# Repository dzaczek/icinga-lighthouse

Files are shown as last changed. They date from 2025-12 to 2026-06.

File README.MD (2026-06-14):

# Icinga-lighthouse 🚨
**A robust, industrial-grade ESP32 monitor for Icinga2, running on LilyGO T-Relay.**

Image ilustration project

icinga-lighthouse turns a LilyGO T-Relay board into a physical alarm system for your infrastructure. It monitors both Services (Critical) and Hosts (Down) through the **Icinga DB Web JSON API** (Icinga *Web*, not the Icinga 2 core API) — so acknowledged, in-downtime and flapping problems are filtered out server-side and never trip the siren. A problem must also be confirmed over several consecutive polls before the siren (Relay 1) fires, with a smart reminder logic afterwards.
-----

## 🌟 Key Features

  * **Dual Monitoring:** Checks the Icinga DB Web API for *Critical Services* AND *Down Hosts*.
  * **Noise-free by design:** Server-side filters (`is_acknowledged=n`, `in_downtime=n`, `is_flapping=n`) mean acknowledged / muted / flapping problems are ignored.
  * **Confirmation threshold:** A problem must be seen *N* polls in a row (default **3**, configurable) before the siren fires — debounces transient/false positives. While confirming, the device polls at a faster "recheck" cadence instead of waiting a full interval.
  * **Business-hours schedule:** Optionally mute the siren outside a schedule of up to 4 day+hour blocks (e.g. Mon–Fri 06–18 *and* Sat 08–14). Alerts are still shown; only the relay is silenced. Clock from Icinga's HTTP `Date` header (no NTP).
  * **Smart Alarm Logic:**
    1.  **Initial Alarm:** Continuous siren for a set time (e.g., 30s).
    2.  **Cooldown:** Silence to preserve sanity.
    3.  **Reminder:** Short bursts (e.g., 15s) every few minutes if the issue persists.
  * **Safe Mode Architecture:**
      * **No Bootloops:** Connection failures do not crash the device.
      * **Brownout Protection:** Disabled brownout detector to handle power spikes from relays.
      * **Heap JSON:** Uses dynamic memory allocation to prevent stack overflows.
  * **Ethernet (W5500) with WiFi fallback:** Auto-detects the LilyGo T-Relay W5500 shield (H671); if present it is used automatically, otherwise the device falls back to WiFi. Selectable in the panel (Auto / Disabled).
  * **Web Configuration Panel:** Fully configurable via a responsive Web UI (WiFi, Ethernet, URLs, Timings, Language).
  * **Multi-language:** Dictionary-based support for **English** and **Polish**.
  * **Manual Test Mode:** Physical buttons in Web UI to toggle relays manually (pauses automation for 60s).

-----

## UX

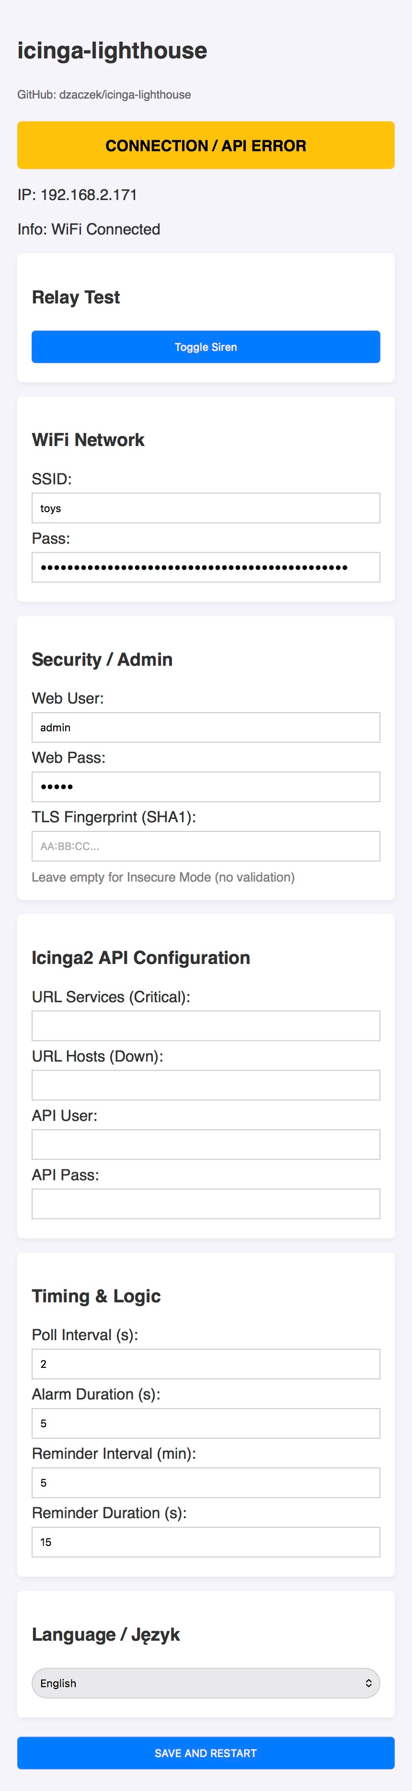
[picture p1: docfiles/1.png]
Image ux


## 🛠️ Hardware & Pinout

**Device:** LilyGO T-Relay (4-Channel ESP32)

| Component | GPIO Pin | Description |
| :--- | :--- | :--- |
| **Relay 1** | **GPIO 21** | **Main Alarm (Siren/Light)** |
| Relay 2 | GPIO 19 | *Disabled / Spare* |
| Relay 3 | GPIO 18 | *Disabled / Spare* |
| Relay 4 | GPIO 05 | *Disabled / Spare* |
| **Status LED** | **GPIO 25** | System Heartbeat / Error Indicator |

### 🔌 Wiring the Siren

> 📐 Full **power & beacon wiring diagram** (24 V supply, mains switch, Osram beacon):
> [`docs/wiring.md`](docs/wiring.md).

Connect your visual/audio signaling device to **Relay 1**:

1.  Connect Power Source (+) to **COM** (Common).
2.  Connect Siren (+) to **NO** (Normally Open).
3.  *The siren will only activate when the alarm is triggered.*

### 🌐 Ethernet — LilyGo T-Relay W5500 Shield (H671)

Plug in the W5500 shield and the device uses wired Ethernet automatically
(DHCP), falling back to WiFi if the shield is absent or the cable is unplugged.
It can be forced off in the panel (Ethernet mode → *Disabled*). Pinout (T-Relay-4):

| W5500 | GPIO | | W5500 | GPIO |
| :--- | :--- | :--- | :--- | :--- |
| SCLK | 22 | | CS | 27 |
| MISO | 13 | | RST | 23 |
| MOSI | 26 | | INT | 36 |

> These pins do not collide with the relays (21/19/18/5) or status LED (25).
> Uses the WIZnet **Ethernet** Arduino library (the ESP32 core 2.x built-in
> `ETH` has no SPI/W5500 support). icingadb-web is queried over plain HTTP on
> the Ethernet path.

-----

## 🧠 Application Logic (Mermaid Diagram)

This flowchart illustrates the core loop of the `icinga-lighthouse` firmware.

```mermaid
graph TD
    Start([System Boot]) --> Init[Disable Brownout & Init WiFi]
    Init --> Loop{Main Loop}

    %% Status LED Logic
    Loop --> LED[Update Status LED]
    LED -- Fast Blink --> ErrState[Error / No Connection]
    LED -- Slow Blink --> OKState[System OK]

    %% Manual Override Check
    Loop --> ManCheck{Manual Mode?}
    ManCheck -- Yes --> WebCtrl[Handle Web Buttons Only]
    WebCtrl --> Loop

    %% Automatic Logic
    ManCheck -- No --> WiFiCheck{WiFi Connected?}
    
    WiFiCheck -- No --> SetErr[Set Network Error Flag]
    WiFiCheck -- Yes --> PollTime{Poll Interval?}
    
    PollTime -- No --> Logic
    PollTime -- Yes --> CheckSvc[GET Icinga Services]
    
    CheckSvc -- Critical Found --> AlarmSet[Set Alarm ACTIVE]
    CheckSvc -- OK --> CheckHost[GET Icinga Hosts]
    
    CheckHost -- Down Found --> AlarmSet
    CheckHost -- OK --> AlarmClear[Set Alarm INACTIVE]
    
    %% Relay Logic Machine
    AlarmSet --> Logic
    AlarmClear --> Logic
    SetErr --> Logic
    
    subgraph Relay State Machine
    Logic[Update Relay Logic] --> StateCheck{Current State}
    StateCheck -- Idle --> R_Idle[Relay OFF]
    R_Idle -- Alarm Active --> R_Init[Relay ON - Initial]
    R_Init -- Time limit reached --> R_Cool[Relay OFF - Cooldown]
    R_Cool -- Reminder time reached --> R_Rem[Relay ON - Reminder]
    R_Rem -- Time limit reached --> R_Cool
    end
    
    Logic --> Loop
```

-----

## 🚦 Status Indicators

The onboard LED (GPIO 25) indicates the current health of the monitor:

  * **🟢 Slow Blink (1s):** System OK. Connected to WiFi and Icinga API reachable.
  * **🔴 Fast Blink (0.2s):** Error. WiFi disconnected OR Icinga API unreachable (check IP/Port).

-----

## ⚙️ Configuration Guide

1.  Connect the device to power.
2.  If not configured, connect to WiFi AP: `icinga-lighthouse-cfg` (Pass: `admin123`).
3.  Open `http://192.168.4.1` (or the assigned IP if connected to your router).
4.  Login (Default: `admin` / `admin`).

### API Setup

The device talks to **Icinga Web 2 / Icinga DB Web** (default port 8080), using HTTP Basic auth with an Icinga Web login. `http://` and `https://` are both supported (https uses an insecure/no-verify TLS connection). `limit=1` keeps the response tiny — the device only needs to know whether *any* unhandled problem exists.

  * **Services URL:** unhandled CRITICAL services.
      * *Example:* `http://192.168.1.100:8080/icingadb/services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`
  * **Hosts URL:** unhandled DOWN hosts.
      * *Example:* `http://192.168.1.100:8080/icingadb/hosts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`
  * **Web User / Pass:** an Icinga Web 2 login (e.g. `admin` / `admin` in the test-env).

> Note: Icinga DB Web is served at the web root (`/icingadb/...`), not under `/icingaweb2/...`, on the official container image.

### Timings & Logic

  * **Poll Interval:** normal query cadence (e.g. 30s).
  * **Fast recheck on problem:** while a fresh problem is being confirmed, poll this fast instead (e.g. 10s).
  * **Confirm threshold:** consecutive problem polls required before the siren fires (default 3).
  * **Alarm Duration:** how long the siren screams initially (e.g., 30s).
  * **Reminder Interval:** how often to remind if the error persists (e.g., every 5 min).
  * **Reminder Duration:** how long the reminder scream lasts (e.g., 15s).

### Business Hours (siren schedule)

The siren can be restricted to a schedule built from up to **4 time blocks**. Each block
is a set of days (tick **Mon–Sun** individually) plus an hour window (**From/To**, To is
exclusive, and To < From spans midnight). The siren is allowed when *now* matches **any**
block — so you can mix rules like *Mon–Fri 06:00–18:00* **and** *Sat 08:00–14:00*. A block
with no days ticked is off; with the whole schedule off the siren runs 24/7.

Alerts are still *detected and shown* in the UI outside the schedule; only the relay is
kept silent. The device clock comes from the **HTTP `Date` header** of Icinga's replies
(works over WiFi and Ethernet alike — no NTP); set the **UTC offset** for your local time.

-----

## 🚀 Deployment

The firmware is a single Arduino sketch (`trelaylaatern.ino`) for the ESP32. Flash it
with **PlatformIO** (CLI, scriptable) or the **Arduino IDE**. Libraries: `ArduinoJson`
(always) and `Ethernet` / WIZnet (only for the W5500 shield).

### Quick start — helper scripts (macOS / Linux)

Two scripts wrap the whole flow (they generate an isolated PlatformIO project in
`.build/`, which is gitignored):

```bash
./build.sh                 # compile only
./flash.sh                 # build + auto-detect the serial port + upload
./flash.sh --monitor       # ...and open the serial monitor afterwards
./flash.sh --erase         # also wipe NVS (clears saved WiFi/Icinga config)
./flash.sh /dev/ttyUSB0    # force a specific port (or set PORT=...)
```

`flash.sh` auto-detects the port (`cu.usbserial*` / `SLAB` / `wchusbserial` on macOS,
`ttyUSB*` / `ttyACM*` on Linux). Needs PlatformIO: `brew install platformio` or
`pipx install platformio`. The manual steps below do the same thing by hand.

### Option A — PlatformIO CLI (macOS / Linux / Windows)

```bash
# 1) Install PlatformIO Core
#    macOS:  brew install platformio        (or: pipx install platformio)
#    Linux:  pipx install platformio        (or: pip install --user platformio)

# 2) Create a project that points at this sketch
mkdir -p build/src && cp trelaylaatern.ino build/src/main.ino
cat > build/platformio.ini <<'INI'
[env:esp32dev]
platform = espressif32
board = esp32dev
framework = arduino
monitor_speed = 115200
upload_speed = 115200          ; some USB-serial bridges fail at 921600
lib_deps =
  bblanchon/ArduinoJson@^6.21.3
  arduino-libraries/Ethernet@^2.0.2
INI

# 3) Find the serial port
#    macOS:  ls /dev/tty.usbserial-*   or  /dev/tty.SLAB_USBtoUART
#    Linux:  ls /dev/ttyUSB*           (add yourself to the 'dialout' group)

# 4) Build, flash, watch the log
cd build
pio run                                              # compile
pio run -t upload --upload-port /dev/tty.usbserial-XXXX
pio device monitor -b 115200 -p /dev/tty.usbserial-XXXX
```

> Tip: a fresh board boots into a WiFi access point `icinga-lighthouse-cfg`
> (password `admin123`); open `http://192.168.4.1` to configure it. To start from
> known defaults instead, wipe stored settings first: `pio run -t erase`.

### Option B — Arduino IDE (macOS / Linux / Windows)

1. Install the **ESP32 board package** (Boards Manager → "esp32" by Espressif).
2. Install libraries (Library Manager): **ArduinoJson**, and **Ethernet** (WIZnet) for the shield.
3. Board: **ESP32 Dev Module**. Port: your USB-serial device.
4. Open `trelaylaatern.ino` and click **Upload**.

### Option C — flash a prebuilt binary with esptool (any OS)

```bash
pip install esptool
esptool.py --port /dev/tty.usbserial-XXXX --baud 115200 write_flash 0x10000 firmware.bin
```

### First-run configuration

1. Connect to the AP `icinga-lighthouse-cfg` (or reach the device IP if it already has
   Ethernet/WiFi) and open the web panel (default login `admin` / `admin`).
2. Set WiFi (or just plug in the W5500 shield for auto Ethernet), the Icinga DB Web URLs
   + login, timings, confirm threshold, and business hours. Save → the device reboots.

### Try it without hardware (Docker/Podman test-env)

A full Icinga DB stack **and** a virtual ESP32 running this exact firmware are in
[`test-env/`](test-env/README.md):

```bash
cd test-env
docker-compose --profile icinga up -d --build   # Icinga DB stack (web on :8080)
./scripts/seed.sh                               # test objects
docker-compose --profile sim up -d --build      # virtual ESP32
./scripts/set-critical.sh                       # fire an alert; watch the relay react
docker logs -f il-esp32-sim | grep -E 'checkIcinga|RELAY'
```

-----

## 🔒 Security notes

- **Brute-force protection:** the web panel throttles every failed login (~0.8 s) and
  locks out after 5 wrong attempts in a row for 60 s (HTTP 429). The lockout is global
  and auto-expires — a sustained guessing attack briefly locks the panel for everyone,
  which is the intended trade-off on a single-admin device.
- **Change the defaults.** Panel login defaults to `admin` / `admin` and the setup AP to
  `admin123`; set your own in the panel (Security / Admin) and WiFi sections.
- **Transport is plaintext.** The panel and the Icinga DB Web polling run over HTTP (the
  ESP32 has no practical TLS server). Keep the device on a trusted VLAN/segment; the
  config AP and basic-auth credentials are sniffable on the local link.

## 🗼 3D-printable lantern

The [`lighthouse3d/`](lighthouse3d/) folder holds the printable lighthouse enclosure that
houses the board — STL parts (base, towers, door, stairs, feet), the assembled STEP model,
a CadQuery source script, and a render preview. Slicing guide (Bambu Studio):
[`lighthouse3d/slicer.md`](lighthouse3d/slicer.md).

## 📝 License

[https://github.com/dzaczek/icinga-lighthouse](https://github.com/dzaczek/icinga-lighthouse)

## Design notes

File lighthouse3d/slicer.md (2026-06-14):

# Printing guide — Bambu Studio (lighthouse parts)

How to slice the lantern parts (especially `04_wieza_gorna.stl`, the upper tower with the
platform, corbel and cable funnel) cleanly. The whole job comes down to **one setting** —
the support **Threshold angle** — plus a note on the screw-insert bosses.

## TL;DR

| Setting | Value |
| :--- | :--- |
| Orientation | **default** — frame/ring flat on the plate, platform up. **Do not flip.** |
| Parameter mode | **Advanced / Expert** (to see the support sub-settings) |
| Layer height | 0.2 mm |
| Walls | 3 wall loops |
| Support | **On**, type **`normal(auto)`** |
| **Support → Threshold angle** | **25°** (drop to 20° if any support still shows under the platform) |
| On build plate only | **OFF** |
| Part cooling (overhang) | PLA ~100 % · PETG ~40–60 % |
| Overhang slow-down | ON, steepest band ~20–30 mm/s |
| Brim | none (the ring gives a big first layer); 3–5 mm only if an edge lifts |

---

## 1. Import & orient

Import `04_wieza_gorna.stl` (or the STEP). **Leave it as-is**: split/frame ring on the plate
at z = 0, platform + railing pointing up. Don't rotate or flip — that orientation is what makes
the funnel self-supporting once the threshold is set.

## 2. Show all options

Top-right, set the parameter mode to **Advanced** (or **Expert**) so the support sub-settings
are visible.

## 3. Filament & quality

Pick your filament (PETG or PLA). 0.2 mm layer height, **3 wall loops**. Infill to taste
(15–20 % gyroid is plenty for an enclosure).

## 4. Support — the key step

Support tab → **Support: On**, **Type: `normal(auto)`**.

**Threshold angle: `25°`.**

> **Why.** Bambu generates support for a surface when its slope **to the bed** is *below* the
> threshold. The funnel/corbel under the platform sit at **~31° from the bed** (≈59° from
> vertical) — right on top of the **~30° default**. Because a curved cone is a mesh of facets,
> some land just under 30° and some just over, so you get **flaky, partial** support smeared
> over the cone. Setting the threshold to **25°** puts the *entire* cone safely above it, so it
> is left support-free, while genuinely flat spots (window-top lintels, platform outer rim,
> railing tops — all ~0° from the bed) still get supported.

- Leave **Top Z distance / XY distance** at the profile defaults.
- **Do not** tick **“On build plate only”** — the small support under the platform rim needs to
  rest on the corbel below it, not the plate.

## 5. Overhang cooling

So the 59°-from-vertical funnel prints clean without support:

- **Cooling:** part-cooling fan high for overhang regions — **PLA ~100 %**, **PETG ~40–60 %**
  (keep PETG moderate so you don't kill layer adhesion).
- **Overhang slow-down:** enable it; put the steepest band around **20–30 mm/s**.
- Optional: raise *min layer time* so thin upper layers get more cooling.

## 6. Slice & verify (don't skip)

Slice → **Preview** → switch to the support/overhang view, then check:

- ✅ **No support columns under the platform** (the funnel/corbel cone). If any remain, lower
  **Threshold angle to 20°**.
- ✅ Support appears **only** at: window-top lintels, the platform outer rim, and railing tops —
  all reachable from outside/top, nothing trapped inside.
- ✅ Scrub the layer slider through the funnel region (≈ z 135–165) and confirm it slices as a
  clean, self-supporting cone.

## 7. Manual cleanup (optional)

- Unwanted auto-support → **Support painting → eraser**, or drop a **Support blocker** over it.
- A flat spot got missed → **Support enforcer**.

## 8. Screw-insert bosses — and dissolvable support

The threshold trick removes support from the funnel; the *remaining* supports are all
**external** (lintels, rim, railing) and snap off by hand — **no soluble filament needed there.**

### Fasteners in this model

The model already uses print-friendly fixing, so **most nut/screw features need no support**:

| Feature | Where | Geometry | Printing |
| :--- | :--- | :--- | :--- |
| **M3 captive-nut slots** | tower↔base tabs, tower-section tabs | horizontal slot **5.75 × 2.8 mm**, nut **slides in** from the bolt hole | **No support** — the 2.8 mm-tall slot bridges only 5.75 mm. Print, then slide the M3 nut in sideways. |
| **M3 heat-set inserts** | upper tower-section tab (Ø4 hole) | straight cylindrical hole | **No support** — melt the brass insert in afterwards. |
| **M6 hex nut pockets** | platform underside, ×3 (lamp mount) | Ø12 hex × **5.6 mm deep**, opens **downward**; central Ø6.6 hole; **roof chamfered to a ~48° cone** | **No support** — the conical roof is self-supporting printed bottom-up. The captive press-fit nut seats on the cone (fine for a light beacon). |

So in practice you **don't** need dissolvable filament for the nuts at all — the M3 slots bridge,
the inserts are straight holes, and the M6 pockets now have a **self-supporting chamfered roof**
(done in [`latarnia_cadquery.py`](latarnia_cadquery.py); the flat ledge was replaced by a ~48° cone).

Soluble/breakaway support is only worth it if a **screw boss traps support inside a blind/deep
cavity** you can't reach. First decide which case you have:

| Insert type | Hole geometry | Needs support? |
| :--- | :--- | :--- |
| **Heat-set threaded insert** (brass, melted in) | straight cylindrical hole, no roof | **No** — print it open, no support, no soluble filament |
| **Captive nut pocket** (hex pocket with a roof) | overhanging roof over a cavity | Yes — and it's hard to clear → soluble/breakaway helps |
| **Self-tapping screw straight into plastic** | plain pilot hole | No |

**Recommended order (cheapest/easiest first):**

1. **Design it out.** Use heat-set inserts in straight holes (zero overhang → zero support), or
   make captive-nut roofs a self-supporting chamfer / teardrop, or open the pocket to one side.
2. **Breakaway interface.** On a multi-material setup (AMS / dual), set only the **support
   interface** to a breakaway material (Bambu *“Support for PLA/PETG”*) and the support **body**
   to your main filament. It releases cleanly from a pocket without water.
3. **Water-soluble (PVA)** — true “dissolve it out”. Use it **only as the support interface**
   (top/bottom interface layers), main filament for the body, to save the (expensive,
   hygroscopic) PVA. Then soak the part in warm water until it dissolves.

**If you go PVA / soluble:**

- Needs a **multi-material printer** (AMS + a printer that allows soluble support, e.g. X1/P1
  with the AMS) — a single-extruder print can't mix two materials.
- Support tab → enable **Support interface**, set **“Interface filament” = PVA** (or breakaway),
  **“Support base filament” = main**. A few interface layers is enough.
- PVA is **hygroscopic** — dry it before use and keep it sealed, or it strings/clogs.
- Temperatures: PVA prints ~**190–215 °C**. It pairs easily with **PLA**; with **PETG** the temp
  gap is larger, so prefer the **breakaway** interface for PETG parts, or print PVA at the low
  end and slow.
- Dissolving is **slow** (warm water, often hours, agitation/replacing water speeds it up).

> Bottom line: for this lantern you most likely **don't** need soluble filament — the funnel is
> handled by the threshold angle, and screw fixing is cleanest with **heat-set inserts in
> straight holes** (no support at all). Reserve PVA/breakaway for genuinely trapped pockets.

## 9. Bed adhesion

The frame ring gives a large first-layer contact area, so adhesion is solid — **no brim needed**
unless an edge lifts, then add a **3–5 mm brim**.

## 10. Alternative — fix it in CAD instead of the slicer

If you'd rather not touch slicer settings on every print, lower `PLUG_BOT_Z` in
[`latarnia_cadquery.py`](latarnia_cadquery.py) so the funnel becomes ~50° from vertical —
self-supporting even at the **default 30°** threshold — and regenerate the STL. Likewise, model
screw bosses as straight holes / teardrop pockets so they never need support.

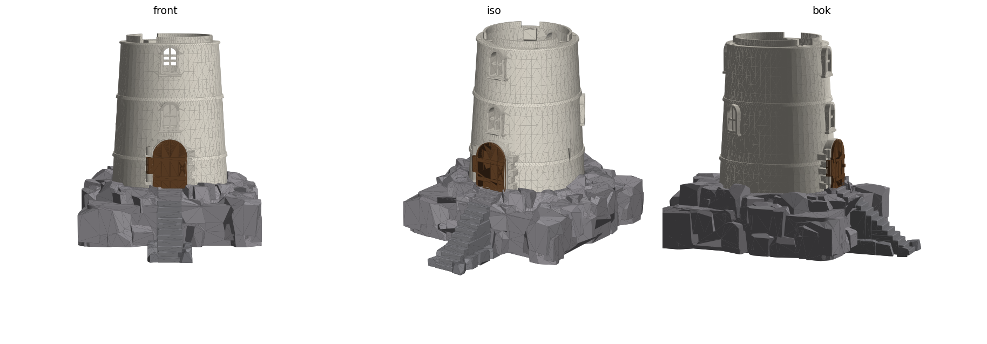
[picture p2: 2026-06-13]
lighthouse3d/preview_skaly.png

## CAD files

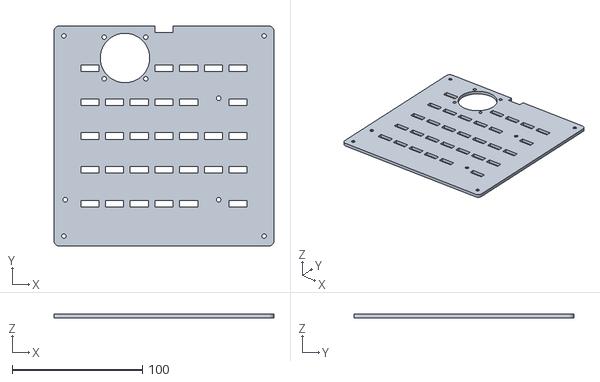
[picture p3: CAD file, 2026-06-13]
lighthouse3d/02_pokrywa_dolna.stl
169.2 x 169.2 x 3.00

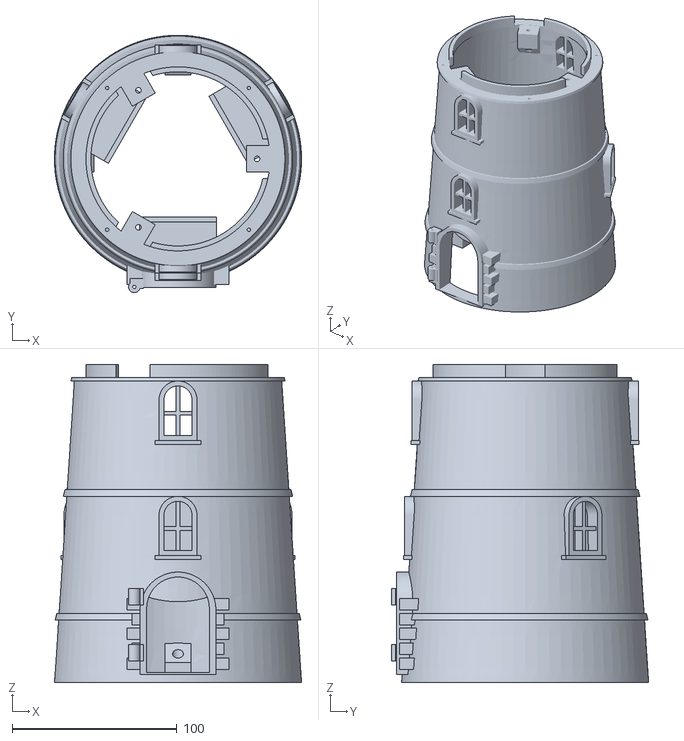
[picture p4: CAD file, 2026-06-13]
lighthouse3d/03_wieza_dolna.stl
150.0 x 156.2 x 193.0

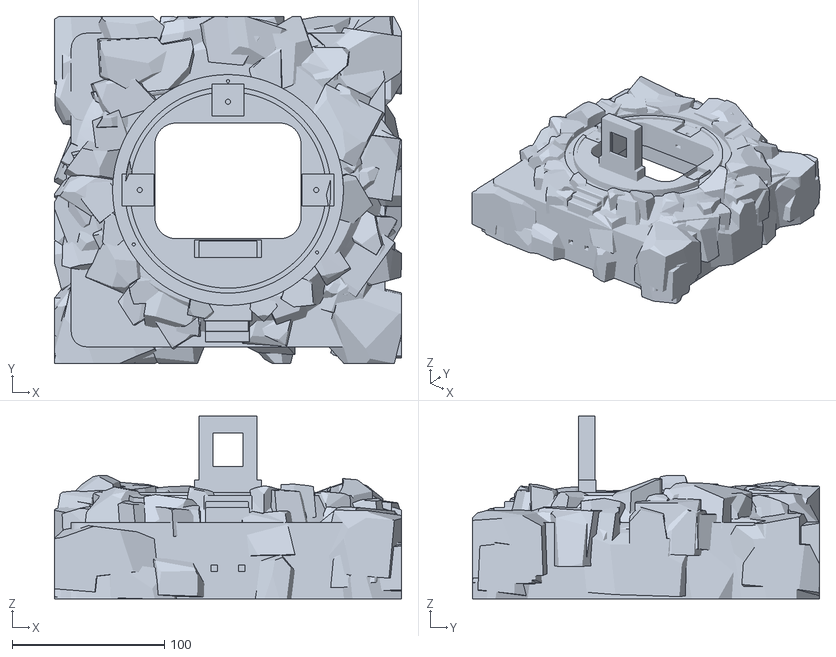
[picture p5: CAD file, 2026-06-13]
lighthouse3d/01_podstawa.stl
228.0 x 228.0 x 120.0

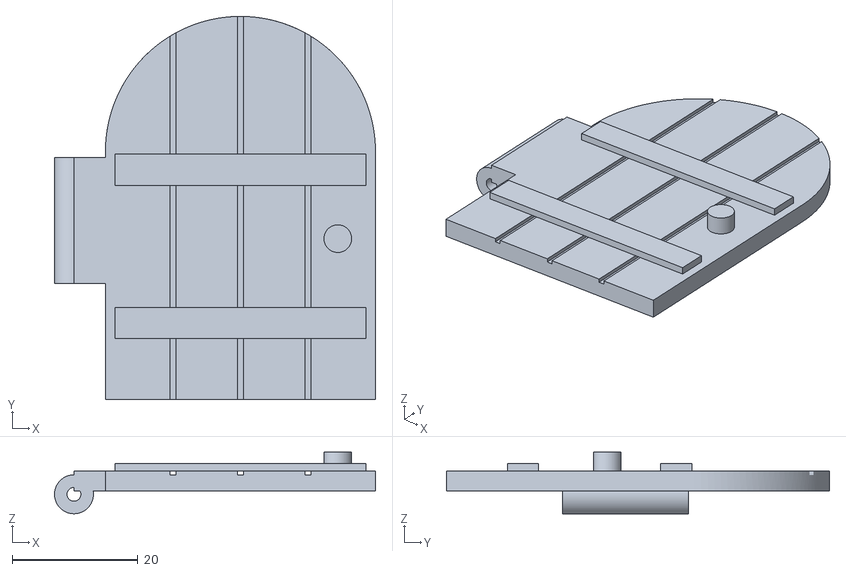
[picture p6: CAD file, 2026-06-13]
lighthouse3d/05_drzwi.stl
51.1 x 61.0 x 9.80

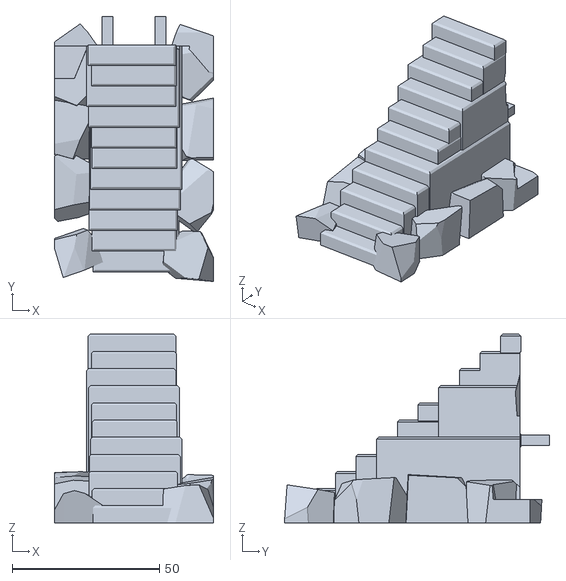
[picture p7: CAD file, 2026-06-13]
lighthouse3d/06_schody_dolne.stl
54.0 x 89.9 x 64.0

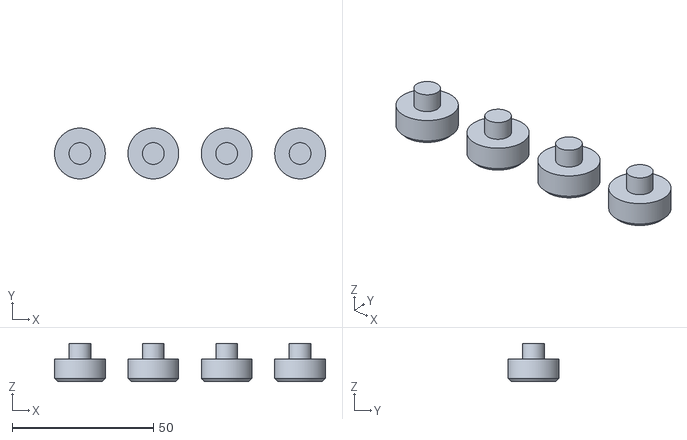
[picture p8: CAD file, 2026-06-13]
lighthouse3d/07_nozki.stl
96.0 x 18.0 x 13.6

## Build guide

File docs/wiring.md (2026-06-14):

# icinga-lighthouse — Power & Beacon Wiring

Wiring for driving an **Osram rotating beacon** from the **LilyGo T-Relay** (ESP32),
powered by a single **24 V** supply, with a mains ON/OFF switch ahead of the PSU.

> ⚠️ **Mains voltage (230 V AC) is lethal.** Build inside a closed, earthed enclosure,
> fit a fuse, and have the AC side wired/checked by a qualified person. Never work on
> the circuit while it is plugged in.

---

## Bill of materials

| Qty | Component | Specification / notes |
| :-: | :--- | :--- |
| 1 | **Power supply** | Mean Well **LRS-100-24** — 24 V DC, 4.5 A (108 W), 85–264 V AC input |
| 1 | **Controller** | LilyGo **T-Relay** (ESP32, 4-channel), **DC-IN 12–24 V** |
| 1 | **Beacon** | Osram rotating beacon, **24 V**, **H1** halogen (~55 W ≈ **2.3 A** @ 24 V) |
| 1 | **Mains switch** | Type **3628**, AC-rated (≥ 250 V, ≥ 6 A) — fitted **on the Line conductor** |
| 1 | **Fuse** | T2A slow-blow on the Line, before the PSU *(recommended)* |
| 1 | **Enclosure** | Metal, bonded to **PE** (protective earth) |
| — | **Wiring** | Mains: ≥ 0.75 mm²; 24 V beacon leg: sized for beacon current |

The siren/beacon is driven by **Relay 1** of the T-Relay (GPIO 21). The board itself is
powered from the **same 24 V rail** via its 12–24 V DC input — no DC-DC converter needed.

---

## Wiring diagram

24 V power and beacon wiring diagram

**Legend** — 🔴 red = Live / +24 V (supply) · ⬛ dark = Neutral / 0 V (return) · 🟢 green = PE (earth).
Relay 1 (GPIO 21) switches +24 V to the beacon; the board is powered from the same 24 V rail.

---

## Connection table (terminal → terminal)

| # | From | To | Conductor |
| :-: | :--- | :--- | :--- |
| 1 | Mains **L (Line)** | **Switch 3628** — in | L |
| 2 | **Switch 3628** — out | LRS-100-24 **L** | **L — the switch lives here** |
| 3 | Mains **N (Neutral)** | LRS-100-24 **N** | N |
| 4 | Mains **PE ⏚** | LRS-100-24 **⏚ (FG)** + metal enclosure | Protective earth |
| 5 | LRS-100-24 **+V** (24 V) | **+24 V rail** | DC |
| 6 | LRS-100-24 **−V** (0 V) | **0 V rail** | DC |
| 7 | **+24 V rail** | T-Relay **DC-IN +** (12–24 V terminal) | Board supply |
| 8 | **0 V rail** | T-Relay **DC-IN −** | Board supply |
| 9 | **+24 V rail** | T-Relay **COM1** (Relay 1 common) | DC |
| 10 | T-Relay **NO1** (Relay 1 normally-open) | Beacon **(+)** | DC, switched |
| 11 | Beacon **(−)** | **0 V rail** | DC |

---

## How it works

The ESP32 firmware energises **Relay 1** (GPIO 21) when an unhandled Icinga problem is
confirmed. The relay's **NO1** contact then closes onto **COM1**, passing **+24 V** to the
beacon's positive lead; the beacon's negative lead is permanently tied to **0 V**, so the
beacon lights/rotates. The controller stays powered the whole time from the same 24 V rail.

Relay 1 switches the **positive (+24 V)** leg; the **0 V** leg is common to the PSU, the
board's DC-IN(−) and the beacon return.

---

## Design notes

1. **Switch on the Line.** The 3628 switch must interrupt **L (Line)**, between mains L and
   the PSU's L terminal (rows 1–2) — never Neutral. A double-pole switch breaking both L and
   N is even better.
2. **Single common 0 V.** PSU `−V`, T-Relay `DC-IN(−)` and the beacon `(−)` all share the
   0 V rail. Relay contacts are isolated from the logic, but the supply ground is common.
3. **`COM1` is a relay terminal, not a power pin.** The relay's `COM / NO / NC` block is a
   **dry, isolated contact**, separate from the board's `DC-IN(±)`. Here `COM1` is fed
   **+24 V** so Relay 1 switches the **high side** to the beacon — do **not** confuse it with
   `DC-IN(−)` / 0 V. (Low-side switching also works: `COM1 = 0 V`, `NO1 → beacon(−)`,
   `beacon(+) → +24 V`.)
4. **Verify the “12–24 V” marking** is on the board's **DC power input** terminal before
   connecting — feeding 24 V to a 5 V-only input would destroy the board.
5. **Halogen inrush.** An H1 bulb's cold filament draws ~8–10× its rated current (~20 A for a
   few ms). The on-board relay contacts (typ. 10 A / 30 V DC) tolerate this occasionally; for
   frequent switching add an external power relay/contactor or an NTC soft-start to spare the
   contacts.
6. **Fuse + earth.** Fit a T2A slow-blow fuse on L before the PSU, and bond the metal
   enclosure to PE.
7. **Supply headroom.** Beacon ~2.3 A + board < 0.2 A ≈ 2.5 A, well within the LRS-100-24's
   4.5 A.

---

## Variants

- **12 V beacon** → use a **LRS-100-12** instead; everything else is identical.
- **230 V AC beacon** → the beacon hangs directly on 230 V switched by Relay 1 (rated
  10 A / 250 V AC). The control side still needs its own 5–24 V supply for the board, and the
  relay contact then carries mains — keep that wiring isolated and fused accordingly.

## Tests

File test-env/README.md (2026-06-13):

# icinga-lighthouse — test environment (Icinga DB stack)

A full, self-contained **Icinga DB** stack plus a **virtual ESP32** that runs the
real `trelaylaatern.ino` firmware compiled for Linux. It lets you verify the
alarm logic end-to-end without any hardware.

The firmware polls **Icinga Web** (the `icingadb-web` JSON API), **not** the
Icinga 2 core API. That is what makes acknowledged / in-downtime / flapping
problems disappear from its view — they are filtered out server-side.

```
icinga2 ──writes──▶ redis ──drained by──▶ icingadb daemon ──▶ MariaDB
                                                                  │
   icingaweb2 (icingadb-web)  ◀── reads redis + MariaDB ──────────┘
        ▲
        │  GET /icingadb/services?...&Accept: application/json
   esp32-sim  (icinga-lighthouse firmware)
```

## Services

| Container | Role | Host port |
| --- | --- | --- |
| `il-mariadb` | MariaDB (icingadb + icingaweb schemas) | – |
| `il-redis` | Redis bus between icinga2 and icingadb | – |
| `il-icinga2` | Icinga 2 core (API + test objects) | 5665 |
| `il-icingadb` | Icinga DB daemon (redis → MariaDB) | – |
| `il-icingaweb2`  | Icinga Web 2 + `icingadb` module | **8080**  |
| `il-esp32-sim` | Virtual ESP32 running the firmware | 8081 |

- **Icinga Web 2:** http://localhost:8080  — login `admin` / `admin`
- **Icinga 2 API:** https://localhost:5665 — `root` / `icinga`
- **icingadb-web JSON API base:** `http://localhost:8080/icingadb` (served at `/`, *not* `/icingaweb2`)

## 1. Start the monitoring stack

```bash
cd test-env
docker-compose --profile icinga up -d --build      # or: podman-compose --profile icinga up -d
```

Wait until everything is healthy (`docker ps`), then seed the test matrix once:

```bash
./scripts/seed.sh
```

### Test object matrix (`icinga2/test-objects.conf`)

All services are **passive**, so a pushed state sticks until changed.

| Service | Seeded state | Firmware should… |
| --- | --- | --- |
| `svc-crit` | OK (trigger on demand) | **fire** the siren when set CRITICAL |
| `svc-ack`  | CRITICAL + acknowledged | **ignore** |
| `svc-dt` | CRITICAL + in downtime | **ignore** |
| `svc-flap` | CRITICAL + flapping | **ignore** |
| `svc-ok` | OK | never fires |

## 2. The JSON API the firmware uses

```bash
# Unhandled criticals (exactly what the firmware queries). limit=1 keeps it tiny.
curl -u admin:admin -H 'Accept: application/json' \
 'http://localhost:8080/icingadb/services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'
```

Response is a top-level JSON array; each element has `name`, `display_name`,
`host.display_name` and a `state` object (`soft_state`, `next_check`,
`is_acknowledged`, `in_downtime`, `is_flapping`, …).

## 3. Run the virtual ESP32

```bash
docker-compose --profile sim up --build
```

It compiles `../trelaylaatern.ino` with the Arduino compatibility shim
(`esp32-sim/MockESP.h`) and polls `http://icingaweb2:8080/icingadb/...`.
Relay changes are printed to the log, e.g. `[GPIO] RELAY Pin 21 -> ON`.
Its web UI (same as the real device) is at http://localhost:8081 (`admin`/`admin`).

## 4. Scenarios

```bash
./scripts/set-critical.sh        # svc-crit CRITICAL  -> siren fires after `confirm_threshold` polls
./scripts/set-ok.sh              # svc-crit OK        -> siren clears
./scripts/ack.sh                 # svc-ack  CRITICAL+ack       (ignored)
./scripts/downtime.sh            # svc-dt   CRITICAL+downtime   (ignored)
./scripts/flap.sh                # svc-flap flapping           (ignored)
```

Watch the firmware react:

```bash
docker logs -f il-esp32-sim | grep -E 'checkIcinga|RELAY'
```

You should see the confirmation counter climb (`confirm=1/3`, `2/3`, `3/3`)
and the relay turn **ON only at `3/3`** — that is the debounce threshold.
While confirming, polls happen at the fast `recheck` cadence, not the slow one.

## Tear down

```bash
docker-compose --profile icinga --profile sim down            # keep data volumes
docker-compose --profile icinga --profile sim down -v         # wipe everything
```

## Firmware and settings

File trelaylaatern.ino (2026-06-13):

/*
 * ======================================================================================
 * Project: icinga-lighthouse (IMPROVED)
 * Description: LilyGO T-Relay 4-Channel Monitor for Icinga2 API
 * Updates: Security Fixes (TLS/Auth), Memory Optimization (Chunked HTML), Reliability
 * ======================================================================================
 *
 * --- SIMULATION MODE (Uncomment to use with Wokwi Simulator) ---
 * // #define SIMULATION_MODE
 * 
 * Instructions:
 * 1. Install "Wokwi for VS Code" extension.
 * 2. Uncomment the line above (#define SIMULATION_MODE).
 * 3. Ensure "Wokwi IoT Gateway" is running on your PC.
 * 4. Press F1 -> "Wokwi: Start Simulation".
 * 
 * Note: In simulation, use your PC's IP address for Icinga, not localhost!
 */

// --- SIMULATION MODE ---
// To run in Podman/Docker (Linux Simulation):
// This block allows compiling the .ino file as a C++ Linux app.
#ifdef LINUX_SIM
  #include "MockESP.h"
  // REMOVED DEFINITIONS FROM HERE TO AVOID REDEFINITION ERROR
#else
  #include <WiFi.h>
  #include <WebServer.h>
  #include <HTTPClient.h>
  #include <WiFiClientSecure.h>
  #include <ArduinoJson.h>
  #include <Preferences.h>
  #include <Ethernet.h>            // WIZnet W5500 (T-Relay W5500 shield H671)
  #include <SPI.h>
  #include "soc/soc.h"
  #include "soc/rtc_cntl_reg.h"
  
  // Configuration for Real ESP32
  // ... (Wokwi or Physical)
#endif    

// --- PIN DEFINITIONS ---
#define RELAY_1_PIN 21
#define RELAY_2_PIN 19
#define RELAY_3_PIN 18
#define RELAY_4_PIN 5
#define STATUS_LED_PIN 25

// --- W5500 Ethernet (LilyGo T-Relay-4 W5500 shield H671) ---
// Pinout per LilyGo pin_config.h / ESPHome yaml. None clash with relays/LED.
#define ETH_W5500_SCLK 22
#define ETH_W5500_MISO 13
#define ETH_W5500_MOSI 26
#define ETH_W5500_CS   27
#define ETH_W5500_RST  23
#define ETH_W5500_INT  36

#define RELAY_ON  HIGH  
#define RELAY_OFF LOW   

Preferences preferences;
WebServer server(80);

// --- LANGUAGE DICTIONARY STRUCT ---
struct LangText {
  String title;
  String st_ok;
  String st_err;
  String st_warn;
  String st_man;
  String t_test;
  String btn_siren;
  String btn_end;
  String sec_net;
  String sec_api;
  String sec_time;
  String lbl_poll;
  String lbl_rchk;
  String lbl_thr;
  String lbl_init;
  String lbl_rint;
  String lbl_rdur;
  String lbl_eth;
  String eth_auto;
  String eth_off;
  String btn_save;
  String msg_saved;
};
LangText txt; // Global object holding current texts

// --- CONFIGURATION ---
String wifi_ssid = "";
String wifi_pass = "";

// Data source: Icinga DB Web JSON API (NOT the Icinga2 core API).
// We ask Icinga *Web* for unhandled problems, so acknowledged / in-downtime /
// flapping objects are filtered out server-side (is_acknowledged=n, etc.).
// http:// uses a plain socket; https:// uses TLS (insecure / no cert check).
// limit=1 keeps the JSON tiny — we only need "is there any problem?".
String icinga_url_svc = "http://192.168.1.100:8080/icingadb/services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";
String icinga_url_host = "http://192.168.1.100:8080/icingadb/hosts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";

String icinga_user = "admin";   // Icinga Web login (not the icinga2 API user)
String icinga_pass = "admin";
String web_user = "admin";
String web_pass = "admin";
String system_lang = "en";
String tls_fingerprint = ""; // Stores SHA1 fingerprint (reserved; TLS is insecure for now)

// Ethernet (W5500): auto-used when the shield is detected, unless disabled here.
bool eth_disabled = false;   // panel toggle: force WiFi even if a W5500 is present

// Timings
unsigned long poll_interval_ms = 30000;       // normal poll cadence
unsigned long recheck_interval_ms = 10000;    // fast re-poll while confirming a fresh problem
unsigned long init_alarm_duration_ms = 30000;
unsigned long reminder_interval_ms = 300000;
unsigned long reminder_duration_ms = 15000;
unsigned long watchdog_timeout_ms = 60000;

// Confirmation threshold: a problem must be seen this many consecutive polls
// before the siren fires. Debounces transient/false positives. Configurable.
int confirm_threshold = 3;

// Business-hours schedule: when enabled, the siren only sounds when the current
// time matches one of the time blocks. Alerts are still detected and shown in
// the UI outside the schedule — only the relay is suppressed. The clock comes
// from the HTTP "Date" header of Icinga's replies (WiFi + Ethernet, no NTP).
//
// Each block = a day mask (bit0=Mon .. bit6=Sun; 0 disables the block) plus an
// [start, end) hour window. The siren fires if ANY block matches now.
#define BH_BLOCKS 4
bool bh_enabled = false;          // restrict siren to the schedule
int  tz_offset  = 0;              // hours added to UTC for local time (e.g. +2)
int  bh_days[BH_BLOCKS] = { 0x1F, 0, 0, 0 };   // default block 1: Mon-Fri
int  bh_s[BH_BLOCKS]    = { 6,  0, 0, 0 };      // start hour (inclusive)
int  bh_e[BH_BLOCKS]    = { 18, 0, 0, 0 };      // end hour (exclusive)

// State
unsigned long last_poll_time = 0;
unsigned long last_successful_data_time = 0;
unsigned long last_wifi_check_time = 0;

// LED & Manual
unsigned long last_blink_time = 0;
bool led_state = false;
unsigned long last_manual_action_time = 0;
bool manual_override_active = false;

// Status
String last_connection_status = "STARTUP";
String last_icinga_object_name = "None";
bool icinga_reachable = false;
bool is_alarm_active = false;
bool is_network_error = false;
bool wifi_connected_mode = false;
int alarm_confirm_count = 0;       // consecutive polls that saw a problem
String last_next_check = "";       // next_check hint from Icinga (for the UI)
bool eth_present = false;          // W5500 chip detected on SPI at boot
bool eth_active = false;           // Ethernet has an IP (updated from net events)
bool config_ap_active = false;     // the config access point is currently up

// Brute-force protection for the web panel: slow every failed login and lock the
// panel after too many in a row. Lockout is global (a sustained attack briefly
// locks everyone out) and auto-expires.
const int AUTH_MAX_FAILS = 5;
const unsigned long AUTH_LOCKOUT_MS = 60000;   // lock 60s after AUTH_MAX_FAILS fails
int auth_fail_count = 0;
unsigned long auth_lock_until = 0;             // millis deadline; 0 = not locked

// Current time, parsed from the HTTP "Date" header (UTC).
bool time_valid = false;
int cur_utc_hour = 0;
int cur_utc_min = 0;
int cur_wday = 0;                  // 0=Sun .. 6=Sat (UTC)

enum AlarmState { STATE_IDLE, STATE_INITIAL_ALARM, STATE_COOLDOWN, STATE_REMINDER_ALARM };
AlarmState current_state = STATE_IDLE;
unsigned long state_start_time = 0;

// Declarations
void loadSettings();
void setLanguage(); 
void setupWiFi();
void setupNetwork();
bool networkUp();
String localIPStr();
void handleRoot();
void handleSave();
void handleToggle();
void checkIcinga();
bool requireAuth();
bool queryIcingaEndpoint(String url, String typeName);
void captureHttpDate(String d);
bool alertsAllowedNow();
String localTimeStr();
void updateRelayLogic();
void ensureWiFiConnection();
void updateStatusLED();
String getUptimeStr();

void setup() {
  // --- SIMULATION MODE ---
  #ifdef LINUX_SIM
    // No Brownout Detector in Sim
    Serial.println("--- VIRTUAL ESP32 RUNNING IN DOCKER ---");
  #else
    // DISABLE BROWNOUT DETECTOR
    WRITE_PERI_REG(RTC_CNTL_BROWN_OUT_REG, 0); 
  #endif 

  Serial.begin(115200);
  delay(1000);
  Serial.println("\n--- icinga-lighthouse v5.3.0 (Icinga DB Web + Ethernet + Schedule blocks) Booting... ---");

  pinMode(RELAY_1_PIN, OUTPUT);
  pinMode(RELAY_2_PIN, OUTPUT);
  pinMode(RELAY_3_PIN, OUTPUT);
  pinMode(RELAY_4_PIN, OUTPUT);
  pinMode(STATUS_LED_PIN, OUTPUT);
  
  digitalWrite(RELAY_1_PIN, RELAY_OFF);
  digitalWrite(RELAY_2_PIN, RELAY_OFF);
  digitalWrite(RELAY_3_PIN, RELAY_OFF);
  digitalWrite(RELAY_4_PIN, RELAY_OFF);
  digitalWrite(STATUS_LED_PIN, LOW);

  loadSettings();

  #ifdef LINUX_SIM
    // Override settings for the Docker test-env AFTER loadSettings()
    // (Preferences are not persisted in the Linux mock). Point at icingadb-web.
    wifi_ssid = "DOCKER_NET";
    wifi_pass = "";
    icinga_user = "admin";
    icinga_pass = "admin";
    icinga_url_svc = "http://icingaweb2:8080/icingadb/services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";
    icinga_url_host = "http://icingaweb2:8080/icingadb/hosts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";
    // Fast cadence so the demo reacts quickly.
    poll_interval_ms = 6000;
    recheck_interval_ms = 2000;
  #endif

  setupNetwork();

  server.on("/", handleRoot);
  server.on("/save", HTTP_POST, handleSave);
  server.on("/toggle", handleToggle);
  server.begin();
  last_successful_data_time = millis(); 
}

void loop() {
  server.handleClient();
  unsigned long current_millis = millis();
  updateStatusLED();

#ifndef LINUX_SIM
  // Keep the Ethernet lease alive and track cable plug/unplug at runtime.
  if (eth_present) {
    static unsigned long last_eth_check = 0;
    if (current_millis - last_eth_check > 3000) {
      last_eth_check = current_millis;
      Ethernet.maintain();
      eth_active = (Ethernet.linkStatus() == LinkON) &&
                   (Ethernet.localIP() != IPAddress(0, 0, 0, 0));
    }
  }
#endif

  if (manual_override_active) {
    if (current_millis - last_manual_action_time > 60000) {
      manual_override_active = false;
    }
  }

  bool ap_mode = (!eth_active && !wifi_connected_mode);
  if (!ap_mode) {
    if (wifi_connected_mode && !eth_active) ensureWiFiConnection();
    if (networkUp()) {
       // Adaptive cadence: while a fresh problem is still being confirmed
       // (count between 1 and threshold-1) poll fast, so we don't wait a full
       // poll_interval for the next confirmation. Otherwise use the normal rate.
       bool confirming = (alarm_confirm_count > 0 && alarm_confirm_count < confirm_threshold);
       unsigned long effective_interval = confirming ? recheck_interval_ms : poll_interval_ms;
       if (current_millis - last_poll_time >= effective_interval) {
         last_poll_time = current_millis;
         checkIcinga();
       }
    } else {
       last_connection_status = eth_present ? "ETH no link" : "No WiFi";
       icinga_reachable = false;
    }
  } else {
    is_network_error = true;
    icinga_reachable = false;
    // Lost every link (e.g. Ethernet-only and the cable was pulled). Raise the
    // config AP so the device stays reachable for reconfiguration.
    if (!config_ap_active) {
      WiFi.softAP("icinga-lighthouse-cfg", "admin123");
      config_ap_active = true;
    }
    last_connection_status = "AP Mode";
  }

  // Soft Watchdog
  if (millis() - last_successful_data_time > watchdog_timeout_ms) {
    if (!is_network_error) {
      is_network_error = true;
      last_connection_status = "Data Timeout";
      is_alarm_active = false; 
      icinga_reachable = false; 
    }
  }

  updateRelayLogic();
}

// --- DICTIONARY LOGIC ---
void setLanguage() {
  if (system_lang == "pl") {
    txt.title = "icinga-lighthouse";
    txt.st_ok = "SYSTEM OK";
    txt.st_err = "ALARM KRYTYCZNY";
    txt.st_warn = "BŁĄD POŁĄCZENIA / API";
    txt.st_man = "TRYB RĘCZNY (TEST)";
    txt.t_test = "Test Przekaźników";
    txt.btn_siren = "Przełącz Syrenę";
    txt.btn_end = "ZAKONCZ TEST";
    txt.sec_net = "Sieć WiFi";
    txt.sec_api = "Konfiguracja Icinga DB Web";
    txt.sec_time = "Czasy i Logika";
    txt.lbl_poll = "Interwał sprawdzania (s)";
    txt.lbl_rchk = "Szybki recheck przy alercie (s)";
    txt.lbl_thr = "Próg potwierdzeń (ile z rzędu)";
    txt.lbl_init = "Czas trwania alarmu (s)";
    txt.lbl_rint = "Przypomnienie co (min)";
    txt.lbl_rdur = "Czas przypomnienia (s)";
    txt.lbl_eth = "Tryb Ethernet";
    txt.eth_auto = "Auto (użyj jeśli wykryty)";
    txt.eth_off = "Wyłączony (wymuś WiFi)";
    txt.btn_save = "ZAPISZ I RESTARTUJ";
    txt.msg_saved = "Zapisano! Restart urzadzenia...";
  } else {
    txt.title = "icinga-lighthouse";
    txt.st_ok = "SYSTEM OK";
    txt.st_err = "CRITICAL ALARM";
    txt.st_warn = "CONNECTION / API ERROR";
    txt.st_man = "MANUAL MODE (TEST)";
    txt.t_test = "Relay Test";
    txt.btn_siren = "Toggle Siren";
    txt.btn_end = "END TEST";
    txt.sec_net = "WiFi Network";
    txt.sec_api = "Icinga DB Web Configuration";
    txt.sec_time = "Timing & Logic";
    txt.lbl_poll = "Poll Interval (s)";
    txt.lbl_rchk = "Fast recheck on problem (s)";
    txt.lbl_thr = "Confirm threshold (consecutive)";
    txt.lbl_init = "Alarm Duration (s)";
    txt.lbl_rint = "Reminder Interval (min)";
    txt.lbl_rdur = "Reminder Duration (s)";
    txt.lbl_eth = "Ethernet mode";
    txt.eth_auto = "Auto (use if detected)";
    txt.eth_off = "Disabled (force WiFi)";
    txt.btn_save = "SAVE AND RESTART";
    txt.msg_saved = "Saved! Rebooting device...";
  }
}

void updateStatusLED() {
  unsigned long now = millis();
  unsigned long interval = icinga_reachable ? 1000 : 200;
  if (now - last_blink_time > interval) {
    last_blink_time = now;
    led_state = !led_state;
    digitalWrite(STATUS_LED_PIN, led_state ? HIGH : LOW);
  }
}

void checkIcinga() {
  bool service_alarm = queryIcingaEndpoint(icinga_url_svc, "Service");

  bool host_alarm = false;
  if (!service_alarm && icinga_url_host.length() > 5) {
      host_alarm = queryIcingaEndpoint(icinga_url_host, "Host");
  }

  bool problem = service_alarm || host_alarm;

  if (problem) {
    if (alarm_confirm_count < confirm_threshold) alarm_confirm_count++;
  } else {
    alarm_confirm_count = 0;
    last_icinga_object_name = "None";
    last_next_check = "";
  }

  // The siren only arms once the problem has been confirmed N polls in a row.
  is_alarm_active = (alarm_confirm_count >= confirm_threshold);

  Serial.println("[checkIcinga] problem=" + String(problem ? 1 : 0) +
                 " confirm=" + String(alarm_confirm_count) + "/" + String(confirm_threshold) +
                 " alarm=" + String(is_alarm_active ? 1 : 0));
}

// --- Time & business hours (time is taken from the HTTP "Date" header) -----

// Parse an IMF-fixdate value, e.g. "Sat, 13 Jun 2026 07:30:00 GMT".
void captureHttpDate(String d) {
  d.trim();
  if (d.startsWith("Date:")) { d = d.substring(5); d.trim(); }
  if (d.length() < 25) return;
  const char* days[7] = { "Sun", "Mon", "Tue", "Wed", "Thu", "Fri", "Sat" };
  String wd = d.substring(0, 3);
  int w = -1; for (int i = 0; i < 7; i++) if (wd == days[i]) w = i;
  if (w < 0) return;
  int hh = d.substring(17, 19).toInt();
  int mm = d.substring(20, 22).toInt();
  if (hh < 0 || hh > 23 || mm < 0 || mm > 59) return;
  cur_wday = w; cur_utc_hour = hh; cur_utc_min = mm; time_valid = true;
}

// True if the siren may sound now. Fails open until the time is known, so a
// fresh boot never silently swallows alerts.
bool alertsAllowedNow() {
  if (!bh_enabled) return true;
  if (!time_valid) return true;
  int h = cur_utc_hour + tz_offset;
  int w = cur_wday;
  while (h >= 24) { h -= 24; w = (w + 1) % 7; }
  while (h < 0)   { h += 24; w = (w + 6) % 7; }
  int dayBit = 1 << ((w + 6) % 7);   // convert 0=Sun..6=Sat to bit0=Mon..bit6=Sun
  for (int i = 0; i < BH_BLOCKS; i++) {
    if (!(bh_days[i] & dayBit)) continue;          // block off or wrong day
    int s = bh_s[i], e = bh_e[i];
    bool inWin = (s <= e) ? (h >= s && h < e) : (h >= s || h < e);  // e<s spans midnight
    if (inWin) return true;
  }
  return false;
}

// Local time as "Www HH:MM" for the UI ("--" if unknown).
String localTimeStr() {
  if (!time_valid) return "--";
  int h = cur_utc_hour + tz_offset;
  int w = cur_wday;
  while (h >= 24) { h -= 24; w = (w + 1) % 7; }
  while (h < 0)   { h += 24; w = (w + 6) % 7; }
  const char* days[7] = { "Sun", "Mon", "Tue", "Wed", "Thu", "Fri", "Sat" };
  char buf[12];
  snprintf(buf, sizeof(buf), "%s %02d:%02d", days[w], h, cur_utc_min);
  return String(buf);
}

// --- Icinga DB Web query (shared parser + WiFi/HTTPClient & Ethernet paths) ---
//
// The URL already carries the state + "not handled" filters, so any element of
// the returned array is a real, unmuted problem. Response is a TOP-LEVEL ARRAY:
//   [ { "name":.., "display_name":.., "host":{"display_name":..},
//       "state":{"soft_state":2,"next_check":"2026-..+00:00",..} }, .. ]

// Parses the problem array from a body stream. Fills last_icinga_object_name /
// last_next_check; returns true if at least one problem is present. Keeps only
// the few fields we need (objects are huge), so memory stays small.
bool applyProblemJson(Stream& stream, String typeName) {
  StaticJsonDocument<256> filter;
  filter[0]["name"] = true;
  filter[0]["display_name"] = true;
  filter[0]["host"]["display_name"] = true;
  filter[0]["state"]["next_check"] = true;

  // Filter keeps only a handful of short fields per element, so even if the URL
  // limit were removed and many problems came back, this stays bounded; with the
  // default limit=1 it is tiny. A NoMemory error is treated as "no problem".
  DynamicJsonDocument doc(4096);
  DeserializationError error =
      deserializeJson(doc, stream, DeserializationOption::Filter(filter));
  if (error) { last_connection_status = "JSON err (" + typeName + ")"; return false; }

  JsonArray arr = doc.as<JsonArray>();
  if (arr.isNull() || arr.size() == 0) return false;

  JsonObject o = arr[0];
  const char* dn = o["display_name"] | o["name"] | "Unknown";
  const char* hn = o["host"]["display_name"] | "";
  String label = String(dn);
  if (typeName == "Service" && hn[0] != '\0') label = String(hn) + "!" + String(dn);
  last_icinga_object_name = typeName + ": " + label;
  last_next_check = String((const char*)(o["state"]["next_check"] | ""));
  return true;
}

#ifndef LINUX_SIM
// HTTP GET over the W5500 (the WIZnet EthernetClient has its own TCP stack and
// can't go through HTTPClient). http:// only — icingadb-web is plain HTTP.
bool queryViaEthernet(String url, String typeName) {
  if (!url.startsWith("http://")) { last_connection_status = "ETH needs http"; return false; }
  String rest = url.substring(7);
  int slash = rest.indexOf('/');
  String hostport = (slash < 0) ? rest : rest.substring(0, slash);
  String path     = (slash < 0) ? "/"  : rest.substring(slash);
  int colon = hostport.indexOf(':');
  String host = (colon < 0) ? hostport : hostport.substring(0, colon);
  int port    = (colon < 0) ? 80       : hostport.substring(colon + 1).toInt();

  EthernetClient client;
  client.setTimeout(4000);
  if (!client.connect(host.c_str(), port)) {
    last_connection_status = "ETH conn fail"; icinga_reachable = false; return false;
  }

  client.print(String("GET ") + path + " HTTP/1.0\r\n");
  client.print("Host: " + host + "\r\n");
  client.print("Authorization: Basic " + base64Encode(icinga_user + ":" + icinga_pass) + "\r\n");
  client.print("Accept: application/json\r\n");
  client.print("Connection: close\r\n\r\n");

  String status = client.readStringUntil('\n');     // "HTTP/1.0 200 OK"
  int code = 0; { int sp = status.indexOf(' '); if (sp > 0) code = status.substring(sp + 1).toInt(); }

  while (client.connected()) {                        // skip headers to blank line
    String line = client.readStringUntil('\n');
    if (line.length() == 0 || line == "\r") break;
    if (line.startsWith("Date:")) captureHttpDate(line);
  }

  if (code != 200) {
    last_connection_status = "ETH HTTP " + String(code);
    icinga_reachable = false; client.stop(); return false;
  }
  icinga_reachable = true; last_successful_data_time = millis();
  is_network_error = false; last_connection_status = "OK (200/eth)";
  bool res = applyProblemJson(client, typeName);
  client.stop();
  return res;
}
#endif

bool queryIcingaEndpoint(String url, String typeName) {
  if (url == "") return false;

#ifndef LINUX_SIM
  if (eth_active) return queryViaEthernet(url, typeName);
#endif

  // WiFi / sim path via HTTPClient. WiFiClientSecure derives from WiFiClient,
  // so a base pointer drives either transport (TLS picked via the vtable).
  bool https = url.startsWith("https");
  WiFiClientSecure secureClient;
  WiFiClient plainClient;
  WiFiClient* client;
  if (https) { secureClient.setInsecure(); secureClient.setTimeout(5); client = &secureClient; }
  else       { client = &plainClient; }

  HTTPClient http;
  http.useHTTP10(true);
  http.setTimeout(4000);

  if (!http.begin(*client, url)) {
    last_connection_status = "Conn Fail (" + typeName + ")";
    icinga_reachable = false;
    return false;
  }
  http.setAuthorization(icinga_user.c_str(), icinga_pass.c_str());
  http.addHeader("Accept", "application/json");
  const char* dateHdr[] = { "Date" };
  http.collectHeaders(dateHdr, 1);

  int httpCode = http.GET();
  bool result = false;
  if (httpCode == HTTP_CODE_OK) {
    icinga_reachable = true;
    last_successful_data_time = millis();
    is_network_error = false;
    last_connection_status = "OK (200)";
    captureHttpDate(http.header("Date"));   // keep device clock fresh
    Stream& stream = http.getStream();
    result = applyProblemJson(stream, typeName);
  } else {
    last_connection_status = "HTTP " + String(httpCode);
    icinga_reachable = false;
  }
  http.end();
  return result;
}
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

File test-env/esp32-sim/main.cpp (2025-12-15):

#include "MockESP.h"

// Include the sketch file directly
// The sketch must have #ifdef LINUX_SIM guards around hardware-specific includes
#include "trelaylaatern.ino"

int main() {
    printf("--- VIRTUAL ESP32 SIMULATOR STARTED ---\n");
    setup();
    while(1) {
        loop();
        // Add a small sleep to prevent 100% CPU usage in the loop
        usleep(10000); // 10ms
    }
    return 0;
}

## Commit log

2025-12-09 Relay check
2025-12-11 Updates: Security Fixes (TLS/Auth), Memory Optimization (Chunked HTML), Reliability Changes to be committed: modified: trelaylaatern.ino
    [trelaylaatern.ino]
2025-12-15 Add test environment with Podman Compose profiles
    - Added esp32-sim: containerized ESP32 emulator with web UI (port 8081)
    - Compiles trelaylaatern.ino as Linux app with Arduino compatibility layer
    - Real HTTP server using cpp-httplib for web interface
    - Connects to Icinga2 via Docker network
    - Updated docker-compose.yml with profiles: icinga and sim
    - Added Icinga2 stack (icinga2, icingaweb2, mariadb) in icinga profile
    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
2026-06-13 v5.1: Icinga DB Web, confirmation threshold, Ethernet (W5500) and business hours
    Firmware (trelaylaatern.ino):
    - Switch data source from the Icinga 2 core API to the Icinga DB Web JSON API
    (/icingadb/services, Accept: application/json). Server-side filters keep
    acknowledged / in-downtime / flapping problems out of view.
    - Confirmation threshold (default 3, configurable) with adaptive fast re-poll
    while a fresh problem is being confirmed.
    - http:// and https:// support; passwords no longer rendered into the HTML.
    - Ethernet via the LilyGo T-Relay W5500 shield (H671): auto-detected and used
    when present, WiFi fallback, panel toggle. Manual GET over EthernetClient
    (Arduino core 2.x ET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
    [trelaylaatern.ino]
2026-06-13 v5.2: business hours as a multi-block day/hour schedule
    Replace the single Mon-Fri window with up to 4 configurable blocks. Each block
    is a day mask (tick Mon-Sun individually) plus a [start, end) hour window; the
    siren is allowed when the current time matches ANY block (e.g. Mon-Fri 06-18
    AND Sat 08-14). To < From spans midnight; a block with no days is off.
    - alertsAllowedNow() iterates blocks; weekday mapped to bit0=Mon..bit6=Sun.
    - Panel: per-block day checkboxes + From/To, plus schedule on/off and UTC offset.
    - Preferences keys bd/bs/be per block; load/save in a loop.
    - README updated.
    Verified in the sim: schedule off -> fires; block excluding now -> muted;
    block including now -> fir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
    [trelaylaatern.ino]
2026-06-13 v5.2.1: robustness/security fixes from code review
    - WiFi hot-standby alongside Ethernet: when WiFi credentials exist, WiFi is also
    brought up even if the W5500 is the active link, so unplugging the cable no
    longer leaves the device unreachable until reboot (setupNetwork).
    - HTML-escape all config values and Icinga object names rendered into the panel
    (esc()), so a quote/<> in an SSID, URL, username or service display name can no
    longer break the page or inject markup.
    - Clamp alarm/reminder durations to >= 1s (init/rint/rdur), matching poll/recheck.
    - Bump the filtered-JSON buffer to 4096 for headroom; a NoMemory parse is already
    treated as "no problem" (fail-safe).
    No memory lea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
    [trelaylaatern.ino]
2026-06-13 v5.2.2: always raise the config AP when all links are lost
    Closes the one remaining gap from the WiFi-standby fix: an Ethernet-only device
    (no WiFi configured) that loses its cable used to show "AP Mode" without actually
    starting an access point, leaving it unreachable until reboot. Now the config AP
    (icinga-lighthouse-cfg / admin123) is raised at runtime whenever every link is
    down, tracked by config_ap_active so it isn't restarted each loop.
    Recap of AP behaviour:
    - WiFi configured but can't connect (~20s) -> AP.
    - WiFi not configured -> AP at boot.
    - Ethernet-only, cable pulled at runtime -> AP (new).
    [trelaylaatern.ino]
2026-06-13 Add build.sh / flash.sh helper scripts
    - build.sh: generate an isolated PlatformIO project in .build/ (gitignored) and
    compile the firmware. Honors BOARD / UPLOAD_SPEED env overrides.
    - flash.sh: build, then auto-detect the serial port (cu.usbserial*/SLAB/
    wchusbserial on macOS, ttyUSB*/ttyACM* on Linux) and upload. Flags: --erase
    (wipe NVS), --monitor (open serial after), or pass a port explicitly.
    - .gitignore: ignore .build/. README: document the scripts under Deployment.
    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
2026-06-13 v5.3.0: brute-force protection for the web panel + 3D lantern files
    Web panel auth hardening (handleRoot/handleSave/handleToggle):
    - New requireAuth(): throttles every failed login by 0.8s and locks the panel
    for 60s after 5 consecutive failures (HTTP 429), auto-expiring. Replaces the
    bare server.authenticate() calls that allowed unlimited, instant guessing.
    Add lighthouse3d/: printable lighthouse enclosure (STL parts, STEP assembly,
    CadQuery source, preview). README: security notes + 3D section.
    Verified in the sim: admin:admin -> 200; wrong password -> 401 x4 then 429 (lock);
    correct password during lockout -> 429. ESP32 build OK.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
    [01_podstawa.stl, 02_pokrywa_dolna.stl, 03_wieza_dolna.stl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]
2026-06-13 docs: add professional wiring diagram (docs/wiring.md)
    English power & beacon wiring guide for the 24 V build: Mermaid diagram
    (GitHub-native, validated), bill of materials, terminal-by-terminal connection
    table, operation, and engineering notes (mains switch on Line, halogen inrush,
    fuse/earth, common 0 V, verify the 12-24 V input marking). Linked from README.
2026-06-14 docs: replace Mermaid wiring diagram with a clean hand-drawn SVG
    Mermaid auto-layout was hard to read. docs/wiring.svg is a static, predictable
    schematic (colour-coded: red = Live/+24 V, dark = Neutral/0 V, green = PE),
    embedded in docs/wiring.md via <img>. Rendered/verified with rsvg-convert.
2026-06-14 docs: clarify COM1 is the (isolated) relay common, not DC−
    Add "relay common · isolated" / "board power" labels on the SVG terminals and a
    design note explaining COM/NO/NC is a dry isolated contact (fed +24 V here for
    high-side switching), distinct from DC-IN(−)/0 V. Notes renumbered.
2026-06-14 3d: fix upper tower (wieza_gorna) — solid fill under platform + clearance
    Regenerate wieza_gorna: add a full inner plug under the platform (tower core +
    corbel interior) re-cut by the cable funnel afterwards, plus a vertical cable
    pass-through — fixes the hollow interior and the gap/clearance issue. Updates
    the CadQuery source, the regenerated STL and the assembled STEP.
2026-06-14 docs: add Bambu Studio slicing guide for the lantern (lighthouse3d/slicer.md)
    Print guide for the upper tower: keep default orientation, lower the support
    Threshold angle to 25° (20° if needed) so the ~31° funnel/corbel prints
    support-free while flat spots still get supported; overhang cooling/slow-down;
    slice-and-verify checklist. Plus a section on screw-insert bosses and when a
    breakaway/PVA soluble support interface is (and isn't) worth it. Linked from README.
2026-06-14 docs(slicer): cover this model's nut pockets & slots
    Add a "Fasteners in this model" table: M3 captive-nut slots (slide-in, bridge
    clean, no support), M3 heat-set inserts (straight holes, no support), and the
    M6 lamp hex pockets (downward-opening with a central Ø6.6 hole → thin annular
    ledge, clears from the open side). Note breakaway/PVA or a CAD chamfer only if a
    pocket is blocked.
2026-06-14 3d: chamfer M6 nut-pocket roofs to ~48° (self-supporting, no support needed)
    Replace the flat annular roof of the three M6 lamp-mount hex pockets with a
    ~48° cone (Ø12 → Ø6.6) so they print bottom-up without support. Regenerated
    04_wieza_gorna.stl and the STEP assembly with CadQuery 2.7.0; verified the
    conical roof in a cross-section. slicer.md updated to reflect the fix.
